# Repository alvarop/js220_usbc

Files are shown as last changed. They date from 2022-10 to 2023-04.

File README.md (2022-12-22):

# Joulescope JS220 USB-C Front Panel

This is a USB-C front panel for the [Joulescope JS220](https://www.joulescope.com/products/js220-joulescope-precision-energy-analyzer)

Here are some renders of what it should look like:

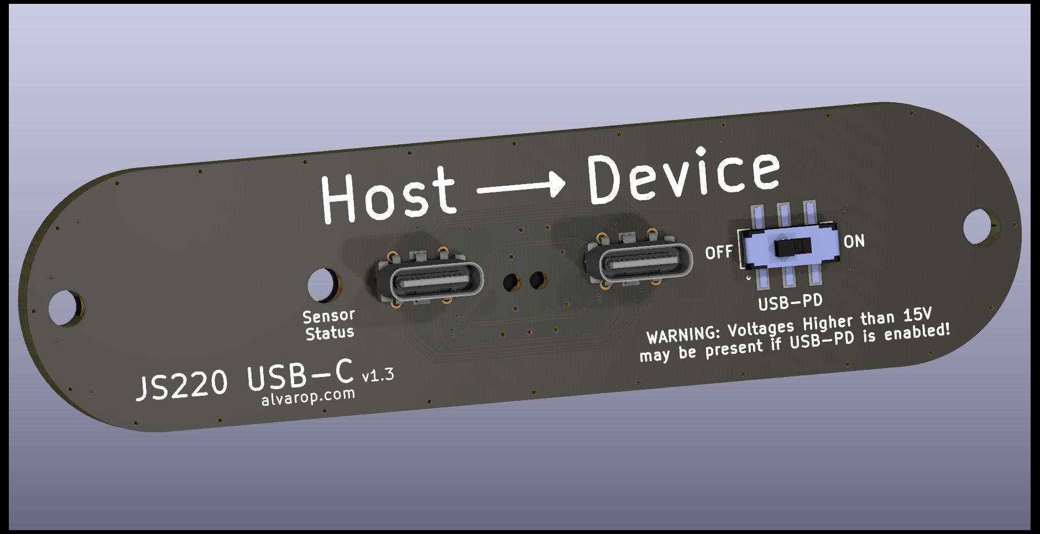
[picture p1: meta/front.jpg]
Board Front


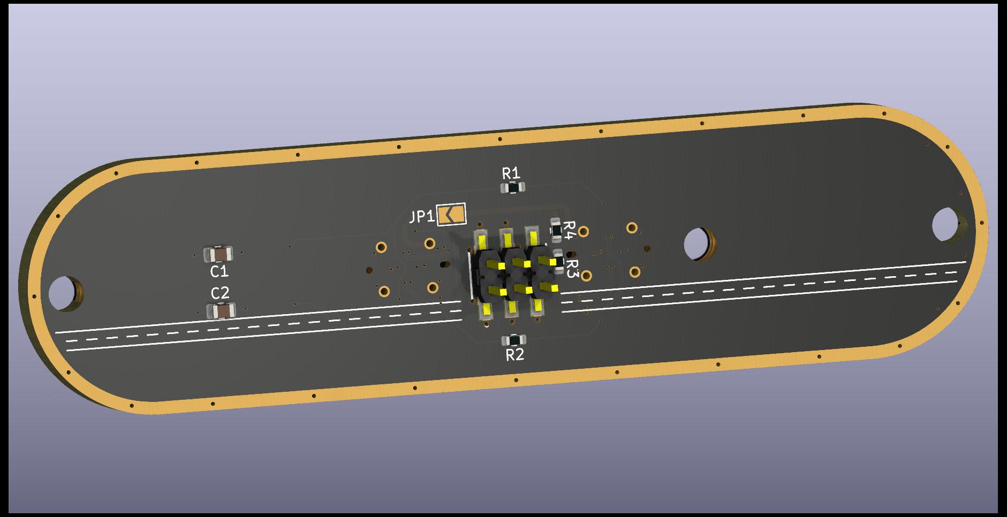
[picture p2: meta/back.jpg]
Board Back


## License
Joulescope JS220 USB-C Front Panel © 2022 by Alvaro Prieto is licensed under CC BY 4.0. To view a copy of this license, visit http://creativecommons.org/licenses/by/4.0/

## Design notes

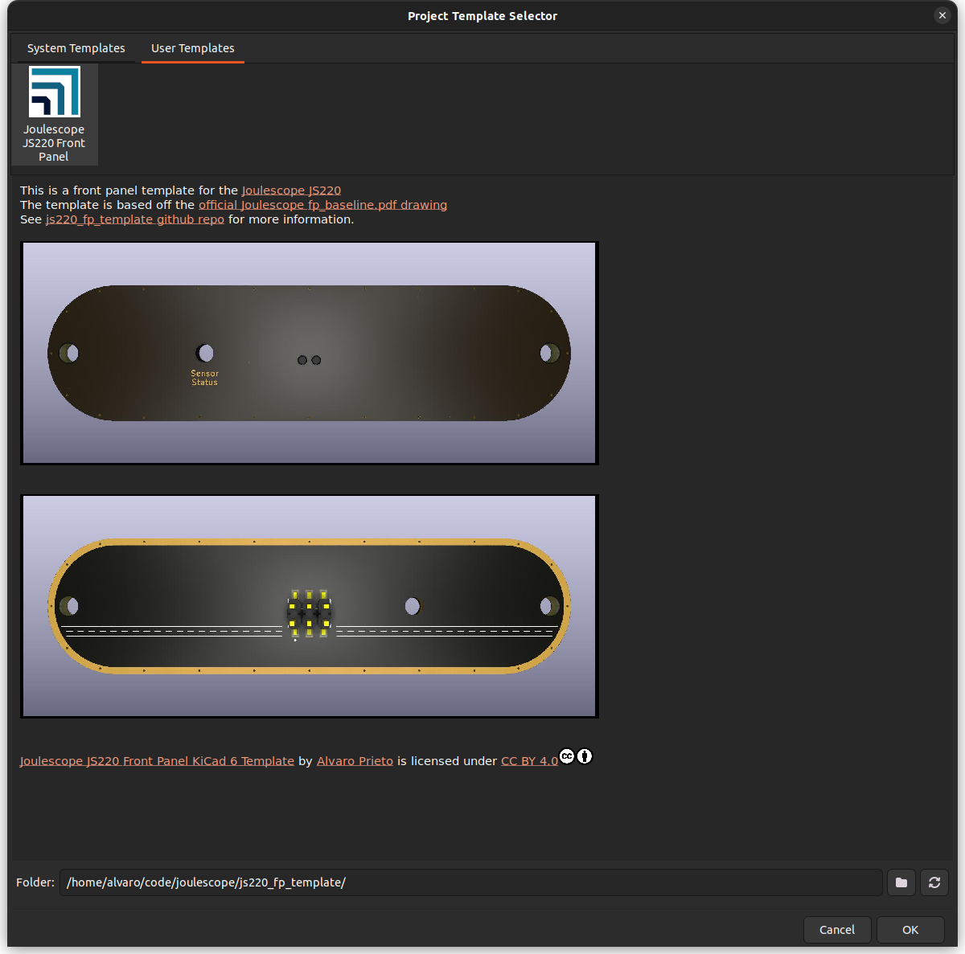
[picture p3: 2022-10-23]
kicad_screenshot.png

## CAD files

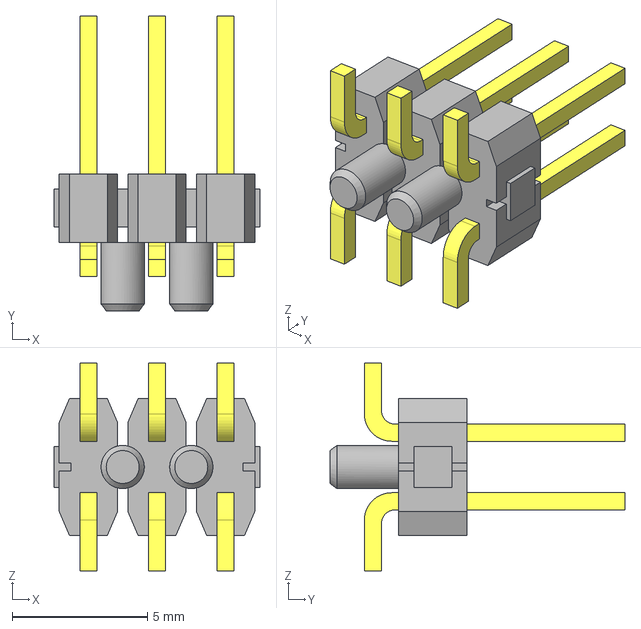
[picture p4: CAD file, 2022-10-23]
3d/TSM-103-01-S-DV-A.step
7.62 x 10.9 x 7.70 mm
T-1S6-16(-01-3-DV)
TSM-103-01-DV-A_body

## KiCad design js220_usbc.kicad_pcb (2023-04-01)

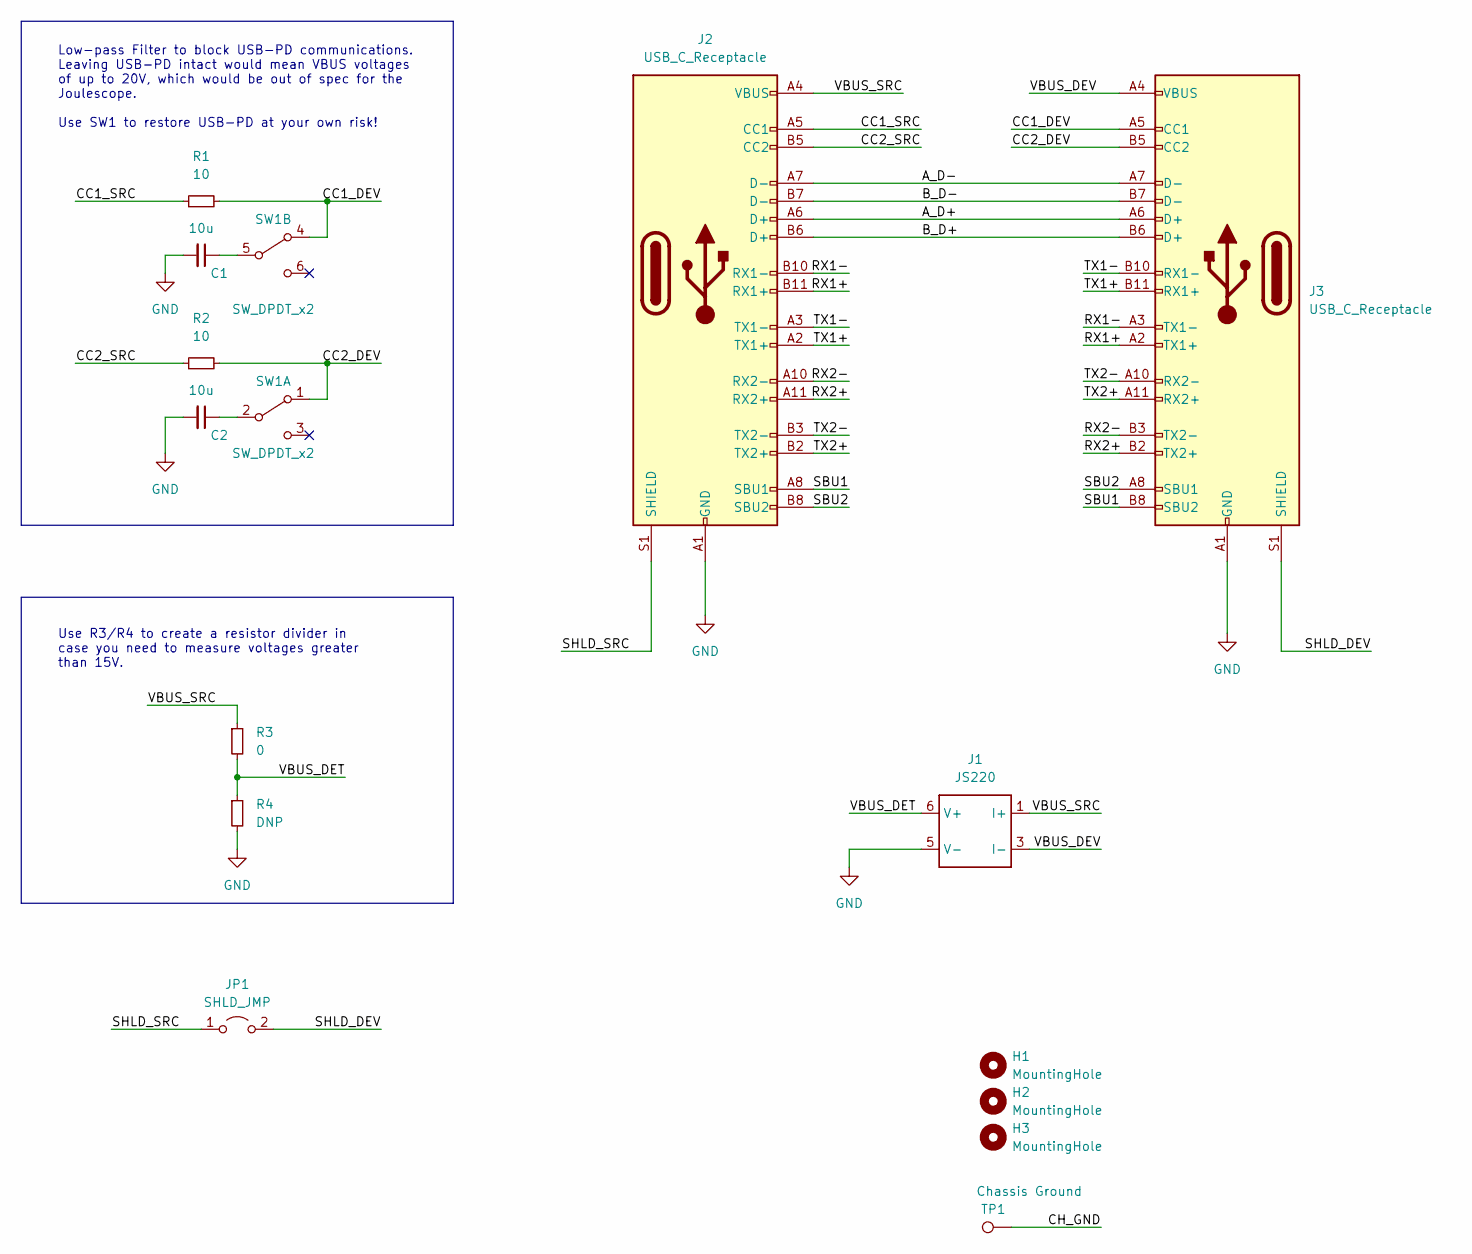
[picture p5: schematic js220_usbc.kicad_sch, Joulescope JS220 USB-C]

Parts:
C1, C2: 10u; C_0805_2012Metric
H1, H2: MountingHole; MOUNTING_HOLE_3.5_W_KO
H3: MountingHole; MOUNTING_HOLE_3.3MM
J1: JS220; SAMTEC_TSM-103-01-S-DV-A
J2, J3: USB_C_Receptacle; TYPE-C-31-M-06
JP1: SHLD_JMP; SolderJumper-2_P1.3mm_Open_TrianglePad1.0x1.5mm
R1, R2: 10; R_0603_1608Metric
R3: 0; R_0603_1608Metric
R4: DNP; R_0603_1608Metric
SW1: SW_DPDT_x2; SW_JS202011SCQN
TP1: Chassis Ground; TINY_TP

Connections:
/A_D+: J2.A6 (D+), J3.A6 (D+)
/A_D-: J2.A7 (D-), J3.A7 (D-)
/B_D+: J2.B6 (D+), J3.B6 (D+)
/B_D-: J2.B7 (D-), J3.B7 (D-)
/CC1_DEV: J3.A5 (CC1), R1.2, SW1.4 (A)
/CC1_SRC: J2.A5 (CC1), R1.1
/CC2_DEV: J3.B5 (CC2), R2.2, SW1.1 (A)
/CC2_SRC: J2.B5 (CC2), R2.1
/CH_GND: TP1.1
/RX1+: J2.B11 (RX1+), J3.A2 (TX1+)
/RX1-: J2.B10 (RX1-), J3.A3 (TX1-)
/RX2+: J2.A11 (RX2+), J3.B2 (TX2+)
/RX2-: J2.A10 (RX2-), J3.B3 (TX2-)
/SBU1: J2.A8 (SBU1), J3.B8 (SBU2)
/SBU2: J2.B8 (SBU2), J3.A8 (SBU1)
/SHLD_DEV: J3.S1 (SHIELD), JP1.2 (B)
/SHLD_SRC: J2.S1 (SHIELD), JP1.1 (A)
/TX1+: J2.A2 (TX1+), J3.B11 (RX1+)
/TX1-: J2.A3 (TX1-), J3.B10 (RX1-)
/TX2+: J2.B2 (TX2+), J3.A11 (RX2+)
/TX2-: J2.B3 (TX2-), J3.A10 (RX2-)
/VBUS_DET: J1.6 (V+), R3.2, R4.1
/VBUS_DEV: J1.3 (I-), J1.4 (I-), J3.A4 (VBUS), J3.A9 (VBUS), J3.B4 (VBUS), J3.B9 (VBUS)
/VBUS_SRC: J1.1 (I+), J1.2 (I+), J2.A4 (VBUS), J2.A9 (VBUS), J2.B4 (VBUS), J2.B9 (VBUS), R3.1
GND: C1.2, C2.2, J1.5 (V-), J2.A1 (GND), J2.A12 (GND), J2.B1 (GND), J2.B12 (GND), J3.A1 (GND), J3.A12 (GND), J3.B1 (GND), J3.B12 (GND), R4.2
unnamed: C1.1, SW1.5 (B)
unnamed: C2.1, SW1.2 (B)

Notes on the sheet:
Low-pass Filter to block USB-PD communications. Leaving USB-PD intact would mean VBUS voltages of up to 20V, which would be out of spec for the Joulescope. Use SW1 to restore USB-PD at your own risk!
Use R3/R4 to create a resistor divider in case you need to measure voltages greater than 15V.

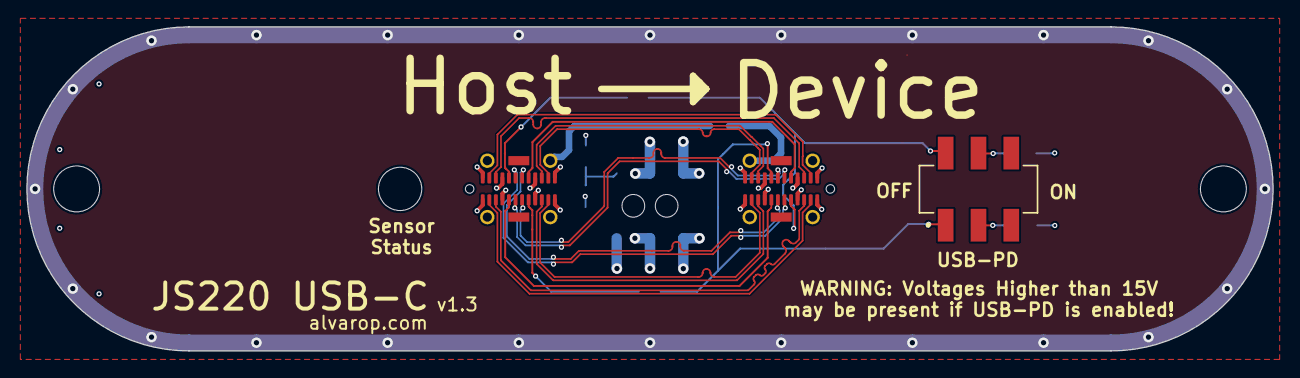
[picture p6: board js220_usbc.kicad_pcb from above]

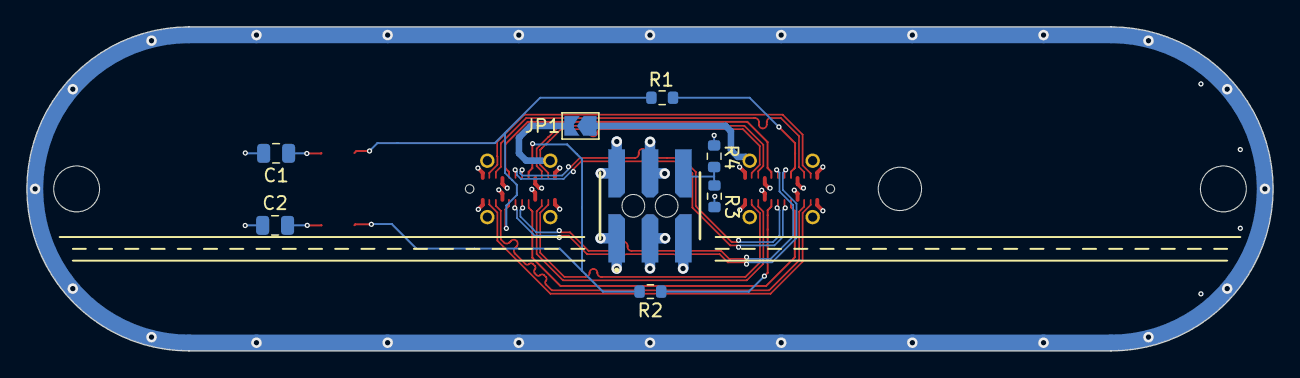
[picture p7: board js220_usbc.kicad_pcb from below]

Board: 4 copper layers, 95.0 x 24.7 mm, 15 parts (8 on the bottom side), 26 nets.

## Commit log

2022-10-23 Initial Commit!
    [TSM-103-01-S-DV-A.step, js220_fp_template.kicad_pcb, js220_fp_template.kicad_sch]
2022-10-23 Update to use JS220 symbol and locked PCB items
    [js220_fp_template.kicad_pcb, js220_fp_template.kicad_sch]
2022-12-22 Forgot to commit all the files...
    [js220_fp_template.kicad_pcb, js220_fp_template.kicad_sch, js220_usbc.kicad_pcb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]
2022-12-22 Fix polarity...
    [js220_usbc.kicad_pcb, js220_usbc.kicad_sch]
2022-12-22 Update readme and silkscreen/version
    [js220_usbc.kicad_pcb]
2023-03-31 v1.2 Done
    [js220_usbc.kicad_pcb, js220_usbc.kicad_sch]
2023-04-01 Fixed length matching for v1.3
    [js220_usbc.kicad_pcb, js220_usbc.kicad_sch]

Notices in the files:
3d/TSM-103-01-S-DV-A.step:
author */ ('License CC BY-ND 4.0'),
